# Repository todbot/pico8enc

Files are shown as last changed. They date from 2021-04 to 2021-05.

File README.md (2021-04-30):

# pico8enc -- 8 rotary encoders on a Raspberry Pi Pico

Turns out you can hook up 8 rotary encoders w/ switches to
Raspberry Pi Pico with no extra hardware. Pretty cool!

With CircuitPython, it becomes pretty easy to actually read these encoders
since all hard, timing-critical work is done inside the C-based `rotaryio`
library that comes standard with CircuitPython.

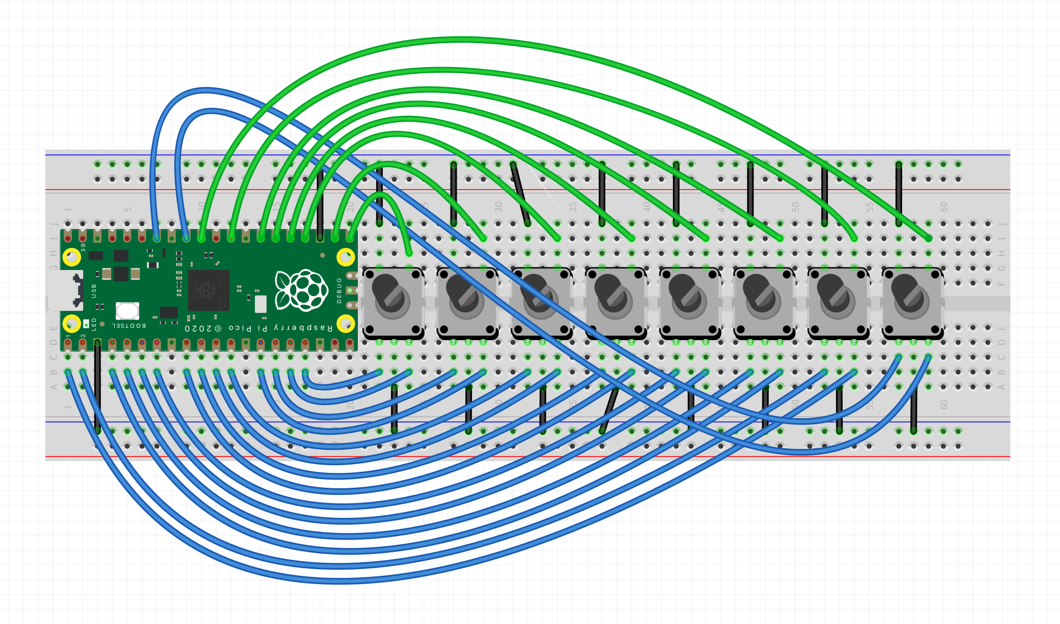
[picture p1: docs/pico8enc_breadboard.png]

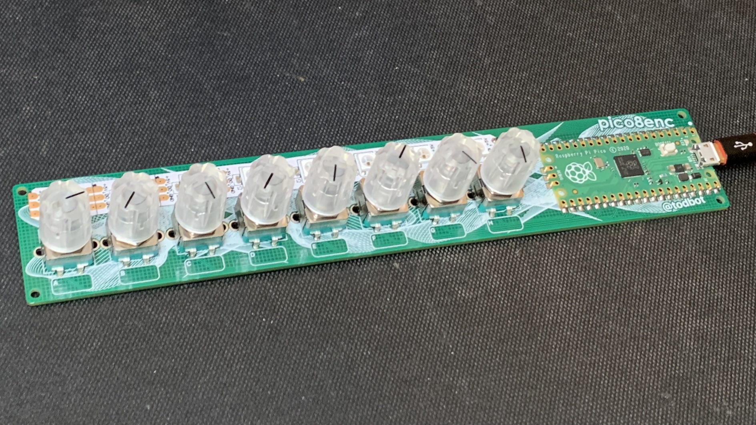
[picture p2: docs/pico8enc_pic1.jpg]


One "twist" to look out for (haha): the two rotary encoder pins must be hooked up
to adjacent pins on the Pico, because of how `rotaryio` uses the Pico's
PIO module to handle reading the encoder pulses.

The core of the code looks like this:
```py
encoder_pins = ( (board.GP12, board.GP13, board.GP16),  # pin A, pin B, pin for switch
                 (board.GP10, board.GP11, board.GP17),
                 (board.GP8, board.GP9, board.GP18),
                 (board.GP6, board.GP7, board.GP19),
                 # ...
                 )
encoders = []
encoder_buttons = []
for pins in encoder_pins:
    pin_A, pin_B, pin_switch = pins
    encoder = rotaryio.IncrementalEncoder( pin_A, pin_B )
    button = DigitalInOut(pin_switch)
    button.pull = Pull.UP
    encoders.append(encoder)
    encoder_buttons.append(button)

while True:
    for i in range(len(encoders)):
      position = encoders[i].position
      button_press = encoder_buttons[i].value

```

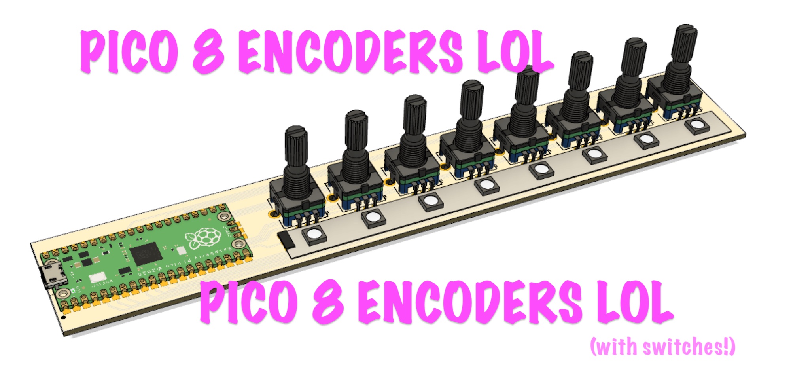
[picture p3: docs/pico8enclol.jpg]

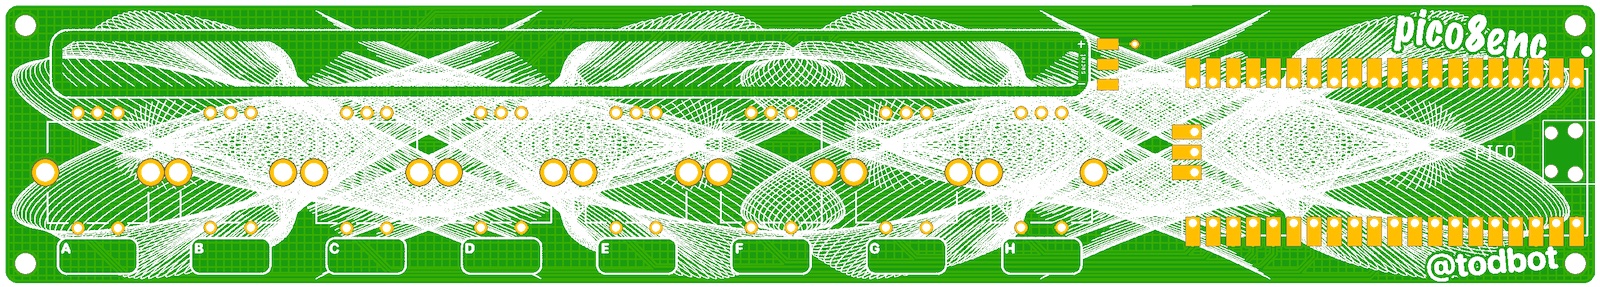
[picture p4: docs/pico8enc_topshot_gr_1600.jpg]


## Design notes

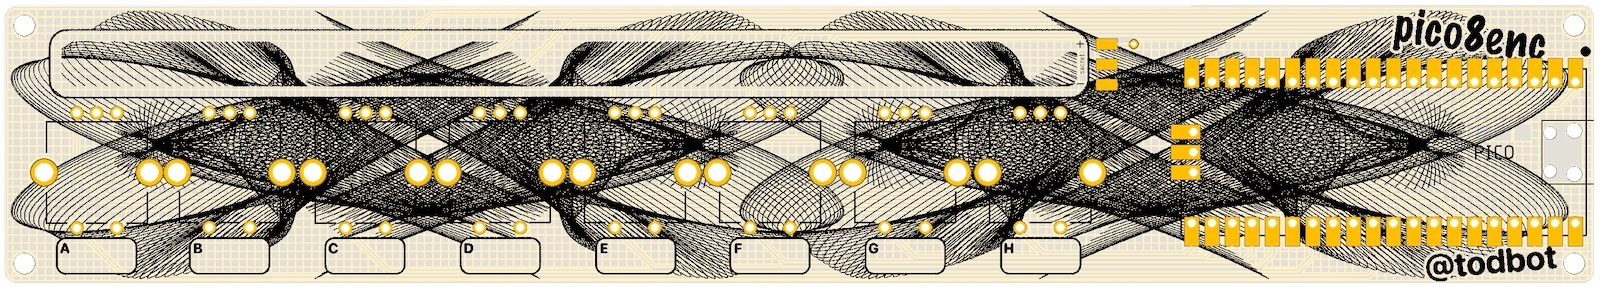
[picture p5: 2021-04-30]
docs/pico8enc_topshot_wh_1600.jpg

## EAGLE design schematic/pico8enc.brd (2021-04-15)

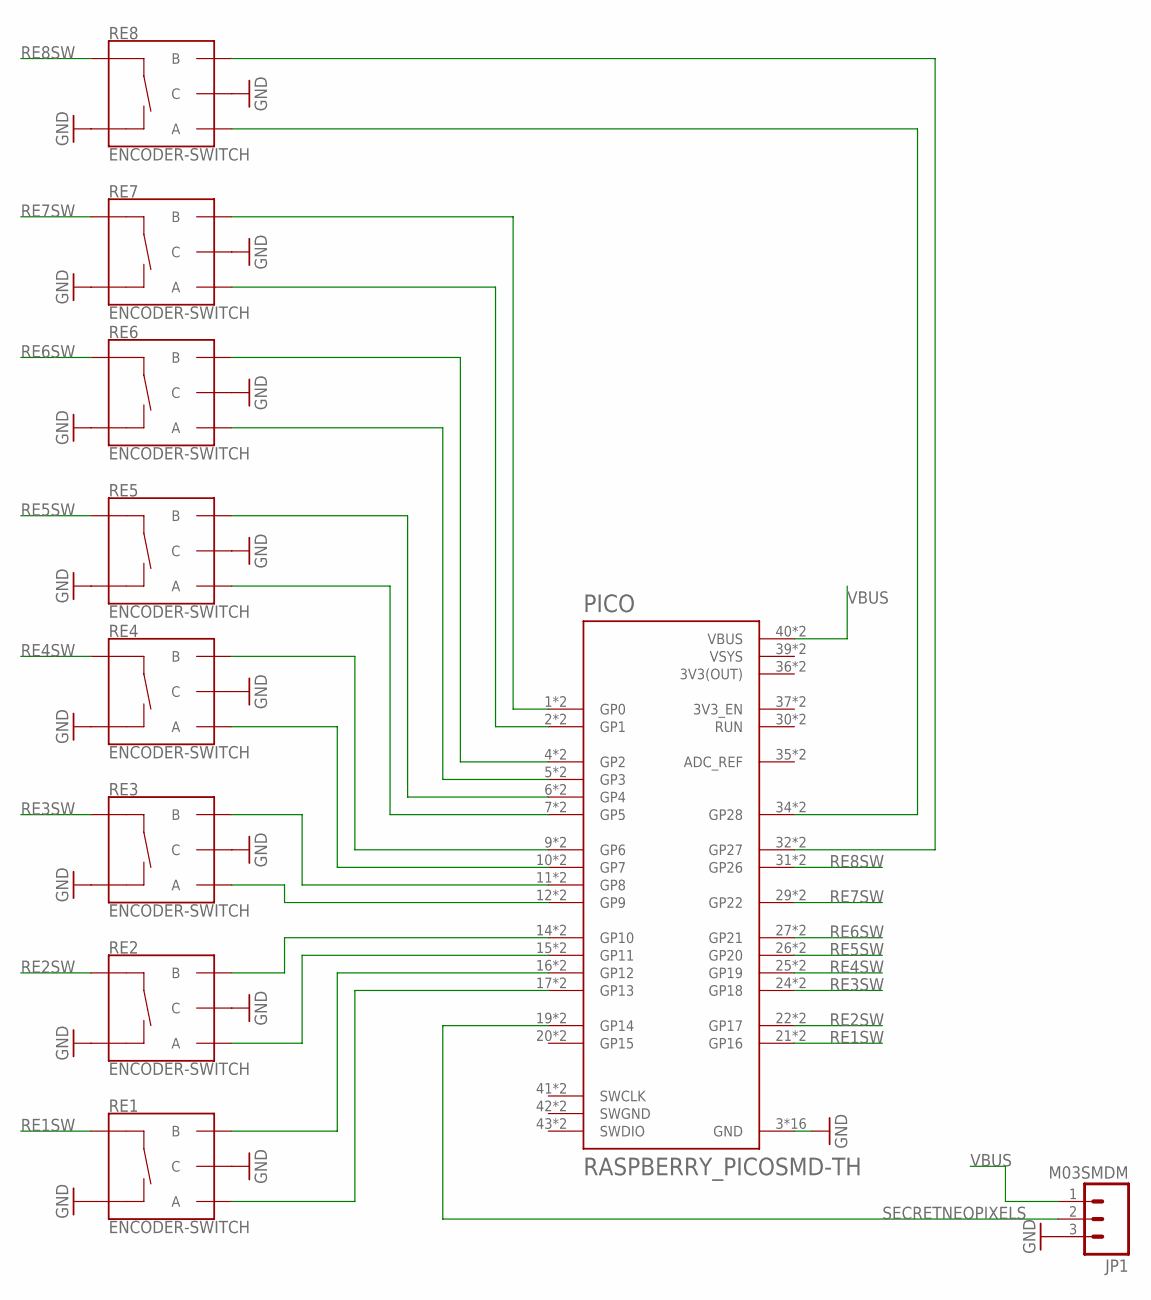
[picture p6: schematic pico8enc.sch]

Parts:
JP1: M03SMDM; 1X03-SMD-MINIMAL
PICO: RASPBERRY_PICOSMD-TH; PICO-PKG
RE1, RE2, RE3, RE4, RE5, RE6, RE7, RE8: ENCODER-SWITCH; ROTARY_ENC_PLAIN

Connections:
3V3(OUT): PICO.36 (3V3(OUT)), PICO.P$36 (3V3(OUT))
GND: JP1.3, PICO.3 (GND), PICO.8 (GND), PICO.13 (GND), PICO.18 (GND), PICO.23 (GND), PICO.28 (GND), PICO.33 (GND), PICO.38 (GND), PICO.P$3 (GND), PICO.P$8 (GND), PICO.P$13 (GND), PICO.P$18 (GND), PICO.P$23 (GND), PICO.P$28 (GND), PICO.P$33 (GND), PICO.P$38 (GND), RE1.C, RE1.SW-, RE2.C, RE2.SW-, RE3.C, RE3.SW-, RE4.C, RE4.SW-, RE5.C, RE5.SW-, RE6.C, RE6.SW-, RE7.C, RE7.SW-, RE8.C, RE8.SW-
unnamed: PICO.17 (GP13), PICO.P$17 (GP13), RE1.A
unnamed: PICO.16 (GP12), PICO.P$16 (GP12), RE1.B
unnamed: PICO.15 (GP11), PICO.P$15 (GP11), RE2.A
unnamed: PICO.14 (GP10), PICO.P$14 (GP10), RE2.B
unnamed: PICO.12 (GP9), PICO.P$12 (GP9), RE3.A
unnamed: PICO.11 (GP8), PICO.P$11 (GP8), RE3.B
unnamed: PICO.10 (GP7), PICO.P$10 (GP7), RE4.A
unnamed: PICO.9 (GP6), PICO.P$9 (GP6), RE4.B
unnamed: PICO.7 (GP5), PICO.P$7 (GP5), RE5.A
unnamed: PICO.6 (GP4), PICO.P$6 (GP4), RE5.B
unnamed: PICO.5 (GP3), PICO.P$5 (GP3), RE6.A
unnamed: PICO.4 (GP2), PICO.P$4 (GP2), RE6.B
unnamed: PICO.2 (GP1), PICO.P$2 (GP1), RE7.A
unnamed: PICO.1 (GP0), PICO.P$1 (GP0), RE7.B
unnamed: PICO.34 (GP28), PICO.P$34 (GP28), RE8.A
unnamed: PICO.32 (GP27), PICO.P$32 (GP27), RE8.B
RE1SW: PICO.21 (GP16), PICO.P$21 (GP16), RE1.SW+
RE2SW: PICO.22 (GP17), PICO.P$22 (GP17), RE2.SW+
RE3SW: PICO.24 (GP18), PICO.P$24 (GP18), RE3.SW+
RE4SW: PICO.25 (GP19), PICO.P$25 (GP19), RE4.SW+
RE5SW: PICO.26 (GP20), PICO.P$26 (GP20), RE5.SW+
RE6SW: PICO.27 (GP21), PICO.P$27 (GP21), RE6.SW+
RE7SW: PICO.29 (GP22), PICO.P$29 (GP22), RE7.SW+
RE8SW: PICO.31 (GP26), PICO.P$31 (GP26), RE8.SW+
SECRETNEOPIXELS: JP1.2, PICO.19 (GP14), PICO.P$19 (GP14)
SWGND: PICO.42 (SWGND), PICO.P$42 (SWGND)
VBUS: JP1.1, PICO.40 (VBUS), PICO.P$40 (VBUS)
VSYS: PICO.39 (VSYS), PICO.P$39 (VSYS)

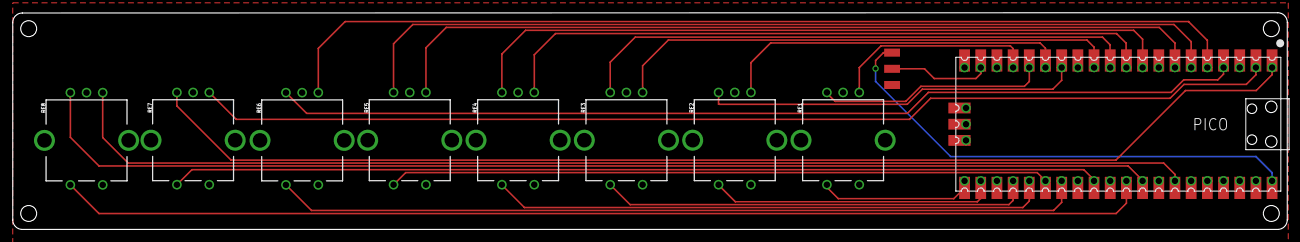
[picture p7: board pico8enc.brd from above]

Board: 2 copper layers, 200.0 x 34.0 mm, 10 parts (0 on the bottom side), 30 nets.

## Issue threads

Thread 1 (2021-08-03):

Error on GP14 and 15

utabi, 2021-08-03:
Hi,
This is awesome simple library for encoders!
I wanted to use GP0 and GP1 for the UART, so I tried to assign GP14 and GP15 to the encoders instead, but I got the error "ValueError: pull masks conflict with direction masks" in Thonny. Perhaps you know the cause of this and that is why you avoided using them. Why can't I use 14 and 15?

todbot, 2021-08-03:
If you're using Thonny I assume you're using MicroPython then? I don't have any experience with that sorry

todbot, 2021-08-03:
Also, which version of CircuitPython or MicroPython are you using?  There was an errata with GP15 on the Pico that I think has a workaround in later CircuitPython. Discussed here:
- https://learn.adafruit.com/getting-started-with-raspberry-pi-pico-circuitpython/faq-and-troubleshooting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
- https://github.com/adafruit/circuitpython/issues/4034

utabi, 2021-08-04:
Thanks, I could fix this problem using CircuitPython 7.0.0-alpha.5 with Thonny. The last CircuitPython version was CircuitPython 6.3.0. Also I tried to use Mu Editor, but it has other error "NameError: name 'rint' is not defined" that I couldn't fix. Anyway I can go ahead! Thank you so much.

todbot, 2021-08-04:
The `'rint' is not defined` error sounds like a `print()` statement that got it's "p" deleted.

Glad you got it working!

Closed 2021-08-04.

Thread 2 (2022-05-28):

Encoders without switches

TuomLarsen, 2022-05-28:
Hello! If one does not need the switches, is it possible to use more the 8 encoders with single Pico?

todbot, 2022-05-28:
8 encoders is the limit if you use `rotaryio` or my little `rp2pio_dualincrementalencoder`, as there's only 8 PIO state machines on the RP2040.

However, if you read the digital inputs by hand like this, then you can have as many as you like:
https://github.com/adafruit/circuitpython/issues/1677#issuecomment-475335465
but that technique is prone to missing steps

TuomLarsen, 2022-05-28:
Thank you! I'm closing this as that's exactly what I was looking for.

Closed 2022-05-28.

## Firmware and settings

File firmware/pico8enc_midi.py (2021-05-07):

#
# pico8enc_midi.py -- 8 rotary encoders on a Pico, no extra hardware
#
# 2021 - @todbot / Tod Kurt - todbot.com
#
# Features:
# - Sends MIDI CCs from each encoder (which CCs configurable below)
# - Knob position represented as white dot on Neopixel strip
# - Each knob has unique color representation
# - Push knob to see its current value on Neopixel strip
#
# Installation:
# - `circup install adafruit_debouncer adafruit_midi adafruit_pioasm neopixel`
# - cp rp2pio_dualincrementalencoder.py /Volumes/CIRCUITPY
# - cp pico8enc_midi.py /Volumes/CIRCUITPY/code.py
#
# Note: this uses 'rp2io_dualincrementalencoder' to use one PIO
# StateMachine per two rotary encoders. This allows us to have a
# PIO StateMachine left over for doing Neopixels
#
# Because of how current pico8enc PCB is laid out, all 8 encoders
# cannot be collapsed into 4 DualEncoder objects. Instead it's:
# EncoderA - single IncrementalEncoder
# EncoderB \_ DualncrementalEncoder
# EncoderC /
# EncoderD \_ DualncrementalEncoder
# EncoderE /
# EncoderF \_ DualncrementalEncoder
# EncoderG /
# EncoderH - single IncrementalEncoder
#

import time
import board
from digitalio import DigitalInOut, Direction, Pull
import rotaryio
import neopixel
import usb_midi
import adafruit_midi
from adafruit_debouncer import Debouncer
from adafruit_midi.control_change   import ControlChange

from rp2pio_dualincrementalencoder import DualIncrementalEncoder

# config for all the knobs
# note that some of these will be controlled by DualIncrementalEncoder
# and some by rotaryio.IncrementalEncoder
knobs_config  = (
    # name, encoder pins (pinA,pinB,switchPin)   #color    # midi CC number 
    ( 'A', (board.GP27, board.GP28, board.GP26), 0xFF00FF, 21 ),  # left-most knob
    ( 'B', (board.GP0,  board.GP1,  board.GP22), 0x0033FF, 22 ), 
    ( 'C', (board.GP2,  board.GP3,  board.GP21), 0xFF3300, 23 ),
    ( 'D', (board.GP4,  board.GP5,  board.GP20), 0x00FFFF, 24 ), 
    ( 'E', (board.GP6,  board.GP7,  board.GP19), 0xFFFF00, 25 ), 
    ( 'F', (board.GP8,  board.GP9,  board.GP18), 0x00FF00, 26 ), 
    ( 'G', (board.GP10, board.GP11, board.GP17), 0x0000FF, 27 ), 
    ( 'H', (board.GP12, board.GP13, board.GP16), 0xFF0000, 28 ),  # right-most knob
)

num_leds = 8
led_pin = board.GP14

midi = adafruit_midi.MIDI(midi_out=usb_midi.ports[1])

# contains all the info needed about a knob
class Knob:
    def __init__(self, name, encoder, encoder_slot, button, color, midi_cc_num, midi_cc_val=0):
        self.name = name
        self._encoder = encoder
        self._encoder_slot = encoder_slot  # for DualEncoder, None if rotaryio
        self.button = button
        self.color = color
        self.midi_cc_num = midi_cc_num
        self.change = 0
        self.midi_mult = 4  # amount to multiply  unused currently
        self._pos = 0
        self._pos_mm = 0  # goes from 0-255
        self.update() # set up the rest of things

    def update(self):
        self.button.update()
        if self._encoder_slot == 0:     # check if dualencoder position 0
            pos,other = self._encoder.positions
        elif self._encoder_slot == 1:   # check if dualencoder position 1
            other,pos = self._encoder.positions
        else:                           # normal rotaryio encoder
            pos = self._encoder.position
        self.change = self._pos - pos
        self._pos = pos
        if self._pos_mm >= 0 and self._pos_mm <= 127:
            self._pos_mm = min(max(self._pos_mm + self.change,0),127)

    @property
    def position(self):
        return self._pos
    
    @property
    def midi_cc_val(self):
        return self._pos_mm #* self.midi_mult

#--------------------------

# set up the knobs, store them in an array
knobs = [None] * len(knobs_config)

# For dual encoders, we read two lines of the config
# knowing that certain pairs of config lines are encoders
# right next to each other
# Unfortunately, the PCB has encoderA and encoderH by themselves
for i in range(1, len(knobs_config)-1, 2): # step by twos because DualEncoders
    (name0, pins0, color0, midi_cc_num0) = knobs_config[i+0]
    (name1, pins1, color1, midi_cc_num1) = knobs_config[i+1]
    pin0_A, pin0_B, pin0_switch = pins0
    pin1_A, pin1_B, pin1_switch = pins1
    #print("DualEncoder:",i+1,i,pin0_A, pin0_B, pin1_A, pin1_B)
    encoderdual = DualIncrementalEncoder(pin0_A, pin0_B, pin1_A, pin1_B)
    button_pin = DigitalInOut(pin0_switch)
    button_pin.pull = Pull.UP
    button0 = Debouncer(button_pin)
    button_pin = DigitalInOut(pin1_switch)
    button_pin.pull = Pull.UP
    button1 = Debouncer(button_pin)
    knobs[i+0] = Knob(name0, encoderdual, 0, button0, color0, midi_cc_num0)
    knobs[i+1] = Knob(name1, encoderdual, 1, button1, color1, midi_cc_num1)

# And here's the setup for encoders A & H
for i in 0,7:  # the two single encoders because of PCB layout silliness
    (name, pins, color, midi_cc_num) = knobs_config[i]
    #print("IncrementalEncoder:",i,pins,color)
    pin_A, pin_B, pin_switch = pins
    encoder = rotaryio.IncrementalEncoder( pin_A, pin_B )
    button_pin = DigitalInOut(pin_switch)
    button_pin.pull = Pull.UP
    button = Debouncer(button_pin)
    knobs[i] = Knob(name, encoder, None, button, color, midi_cc_num) 
    
leds = neopixel.NeoPixel(led_pin, num_leds, brightness=0.1, auto_write=False)
# testing
leds.fill(0xff6600); leds.show();
time.sleep(0.25)
leds.fill(0); leds[0] = (0,0xff,0); leds[len(leds)-1] = (0,0xff,0); leds.show()
time.sleep(0.25)
leds.fill(0); leds.show()

# convert midi cc value to a led strip info
def val_to_leds(color,val):
    di = 128 // len(leds)  # 128 values in midi CC
    i = len(leds)-1 - (val // di)  
    leds.fill(color)
    leds[i] = 0xffffff
    leds.show()

print("pico8enc - 8 rotary encoders midi controller")
print("Knobs configured:")
for i in range(len(knobs)):
    k = knobs[i]
    print(f"knob:{k.name} MIDI CC:{k.midi_cc_num} color:#{k.color:06x}")

last_touch_time = 0 

while True:
    for knob in knobs:
        knob.update()
        diff = knob.change
        if diff or knob.button.fell or knob.button.rose:
            val_to_leds(knob.color, knob.midi_cc_val)
            # actually send midi control change
            midi.send(ControlChange(knob.midi_cc_num, knob.midi_cc_val))
            butpress = '-'
            if knob.button.fell: butpress = 'v'
            if knob.button.rose: butpress = '^'
            print(f"MIDI CC:{knob.midi_cc_num}={knob.midi_cc_val:3d} knob:{knob.position} d:{diff} but:{butpress}")
            last_touch_time = time.monotonic()

    # display knob colors on idle
    if time.monotonic() - last_touch_time > 2:
        for i in range(len(knobs)):
            leds[len(leds)-1-i] = knobs[i].color
        leds.show()
        


    

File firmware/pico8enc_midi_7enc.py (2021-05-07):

#
# pico8enc_midi.py -- 8 rotary encoders on a Pico, no extra hardware
#
# 2021 - @todbot / Tod Kurt - todbot.com
#

import time
import board
from digitalio import DigitalInOut, Direction, Pull
import rotaryio
from adafruit_debouncer import Debouncer
import neopixel
import usb_midi
import adafruit_midi
from adafruit_midi.note_off         import NoteOff
from adafruit_midi.note_on          import NoteOn
from adafruit_midi.control_change   import ControlChange

midi = adafruit_midi.MIDI(midi_out=usb_midi.ports[1])

# config for all the knobs
# OOPS: Looks like CircuitPython can either support EITHER
# - 8 rotary encoders and NO neopixels, OR
# - 7 rotary encoders and neopixels
# DANGIT
knobs_config  = (
    #  encoder pins (pinA,pinB,switchPin)   #color    # midi CC number # mult
#    ( (board.GP12, board.GP13, board.GP16), 0xFF00FF, 28 ),  # right-most knob
    ( (board.GP10, board.GP11, board.GP17), 0x0000FF, 27 ), 
    ( (board.GP8,  board.GP9,  board.GP18), 0x00FF00, 26 ), 
    ( (board.GP6,  board.GP7,  board.GP19), 0xFFFF00, 25 ), 
    ( (board.GP4,  board.GP5,  board.GP20), 0x00FFFF, 24 ), 
    ( (board.GP2,  board.GP3,  board.GP21), 0xFF3300, 23 ),
    ( (board.GP0,  board.GP1,  board.GP22), 0x0033FF, 22 ), 
    ( (board.GP27, board.GP28, board.GP26), 0xFF00FF, 21 ),  # left-most knob
)

num_leds = 8
led_pin = board.GP14

# contains all the info needed about a knob
class Knob:
    def __init__(self, encoder, button, color, midi_cc_num, midi_cc_val=0):
        self.encoder = encoder
        self.button = button
        self.color = color
        self.midi_cc_num = midi_cc_num
        self._midi_cc_val = midi_cc_val
        self.change = 0
        self.encoder.position = 127
        self.mult = 4
        self._last_val = self.encoder.position

    def update(self):
        self.button.update()
        pos = self.encoder.position
        self.encoder.position = min(max(pos,0),127)
        self.change = self._last_val - pos
        self._last_val = pos

    @property
    def position(self):
        return 127 - self.encoder.position
    
    @property
    def midi_cc_val(self):
        self._midi_cc_val = 2 * self.position
        return self._midi_cc_val
    
#--------------------------

# # set up the knobs, store them in an array
knobs = []
for config in knobs_config:
    (pins, color, midi_cc_num) = config
    pin_A, pin_B, pin_switch = pins
    encoder = rotaryio.IncrementalEncoder( pin_A, pin_B )
    button_pin = DigitalInOut(pin_switch)
    button_pin.pull = Pull.UP
    button = Debouncer(button_pin)
    knobs.append( Knob(encoder, button, color, midi_cc_num) )

leds = neopixel.NeoPixel(led_pin, num_leds, brightness=0.2, auto_write=False)

# testing
leds.fill(0xff6600); leds.show();
time.sleep(0.5)
leds.fill(0); leds[0] = (0,0xff,0); leds[len(leds)-1] = (0,0xff,0); leds.show()
time.sleep(0.5)
leds.fill(0); leds.show()

# convert midi cc value to a led strip info
def val_to_leds(color,val):
    leds.fill(color)
    i = len(leds)-1  - (val // len(leds))
    leds[i] = 0xffffff
    leds.show()


print("pico8enc - 8 rotary encoders midi controller")
while True:
    for knob in knobs:
        knob.update()
        diff = knob.change
        if diff or knob.button.fell or knob.button.rose:
            val_to_leds(knob.color, knob.midi_cc_val)
            midi.send(ControlChange(knob.midi_cc_num, knob.midi_cc_val))
            butpress = '-'
            if knob.button.fell:
                butpress = 'v'
            if knob.button.rose:
                butpress = '^'
            print("MIDI CC#:%d = %d knob:%d diff:%d but:%s" % (knob.midi_cc_num, knob.midi_cc_val, knob.position, diff, butpress))


    

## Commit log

2021-04-06 some ideas
    [pico8enc.brd, pico8enc.fzz, pico8enc.sch]
2021-04-13 update and made public since it made the CircuitPython newsletter
    [pico8enc.brd, pico8enc.fzz, pico8enc.sch]
2021-04-13 pin clarification
2021-04-15 pcb cleanup
    [pico8enc.brd, pico8enc.sch]
2021-04-30 pcb syncup
2021-04-30 first cut at MIDI controller UI. looks like maybe cannot do 8 encoders and neopixel? PIO limit?

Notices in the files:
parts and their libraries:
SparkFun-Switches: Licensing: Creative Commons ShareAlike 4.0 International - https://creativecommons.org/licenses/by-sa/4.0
